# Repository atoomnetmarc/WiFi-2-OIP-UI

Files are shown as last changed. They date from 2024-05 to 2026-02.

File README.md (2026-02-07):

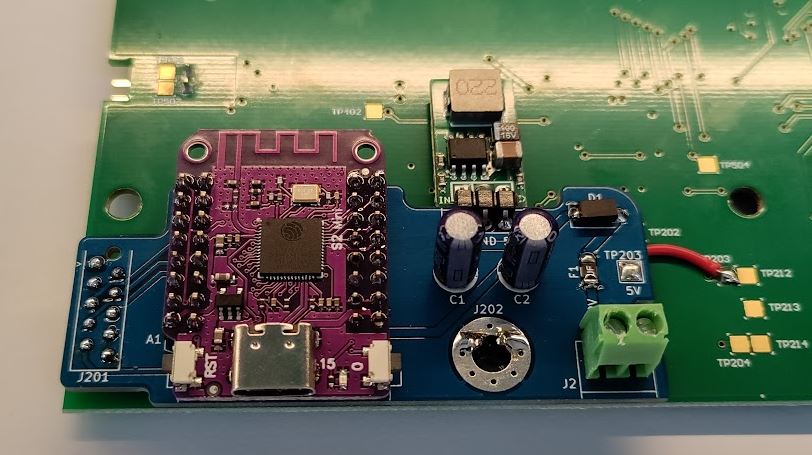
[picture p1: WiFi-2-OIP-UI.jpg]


# Status

Unfinished. Untested.

# What?

This is a **WiFi-connected display with LEDs** that gives new life to a reclaimed display board from an obsolete [Octalarm-IP](https://www.adesys.nl/en/product-octalarm-ip-adesys2).

The project consists of:

- A custom PCB that hosts an **ESP32-S2** microcontroller with WiFi connectivity
- A **128x64 LCD display** (Crystal Clear Technology G64128S18YBW00 with NT7534 controller)
- **20 red and 20 green LEDs** for status indication
- **Backlight control** for the LCD

The ESP32-S2 controls the display and LEDs via SPI.

# BOM

See: [Kicad/bom/ibom.html](Kicad/bom/ibom.html)

## BOM remarks

U1 should be a 5V buck converter in the footprint of a TO-220. It should be capable of outputting 5V at 1A. Input voltage should be greater than 12V.

J201 are 2 pieces of 1x05 2.54mm pp low profile (7.5mm) pin header instead of a Micro-MaTch connector.

For connecting TP203 you need 2cm of red wire.

The ESP32-S2 should come with 2 pieces of 2x08 2.54mm pin headers. Discard them and order 4 pieces of 1x08 2.54mm pp low profile (7.5mm) pin headers.

J201 Phoenix contact 1803277+1851999 can also be 1803277+1803578.

# Soldering and assembly instructions

Solder the pin headers on the ESP32-S2, use some old IDC connectors to perfectly align the headers. Like this:

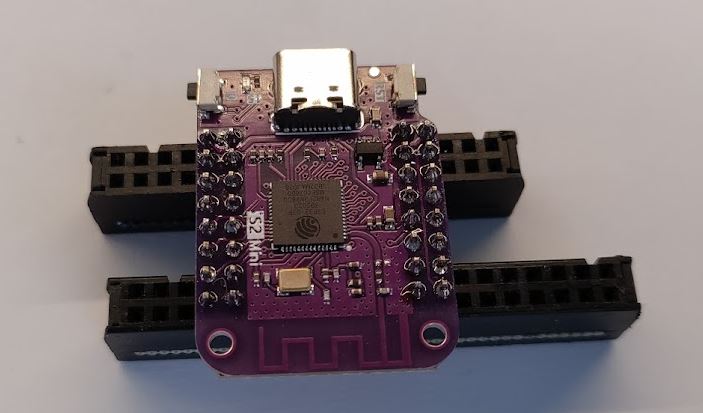
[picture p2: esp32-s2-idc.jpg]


Solder F1, D1. Solder U1 (the buck converter) laying flat (PCBs are now on the same plane). Cut pins (6 cuts) of U1 flush with PCB. Solder J2, C1 and C2. Cut pins of J2 flush with PCB. Solder one end of the red wire to TP203 on the bottom. The right side of the PCB now look like this:

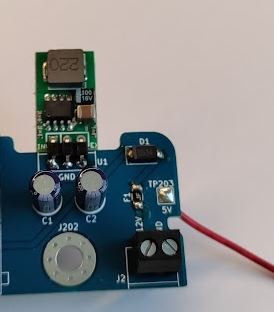
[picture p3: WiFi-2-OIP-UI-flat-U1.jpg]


Set your lab power supply to 12V CV, 0.25A CC. Then connect 12V to J2. Observe less than 10mA current. Measure 5V between TP203 and ground. Disconnect power supply.

Passed? Now solder A1 (the ESP32-S2 module). Do you not use low profile pin headers? Then cut pins flush with PCB. Works best before soldering.

Connect power supply again. Observe about 10mA current if ESP32-S2 is new and empty or about 40mA when flashed with firmware. Disconnect power supply.

Desolder the J201 MicroMatch 1.27mm socket from the display board.

Gently clean the PCB and the ESP32-S2 if you want.

Connect this PCB to the back of the display board using 2 pieces of low profile 1x5 2.54mm pin headers in the J201 footprints of both PCBs. The hole J202 on both PCB should almost align. But do not solder the header yet.
First solder a 1x02 2.54mm pin header on J202 of both PCBs to keep PCBs separated. Now solder the J201 pin header.

Solder the red wire onto the TP203 pad of the display board.

Connect power supply again. Observe about 20mA current (or 50mA when flashed). Disconnect power supply.

Make sure none of the pins (ESP32-S2, U1, J2) of this PCB touch display board:

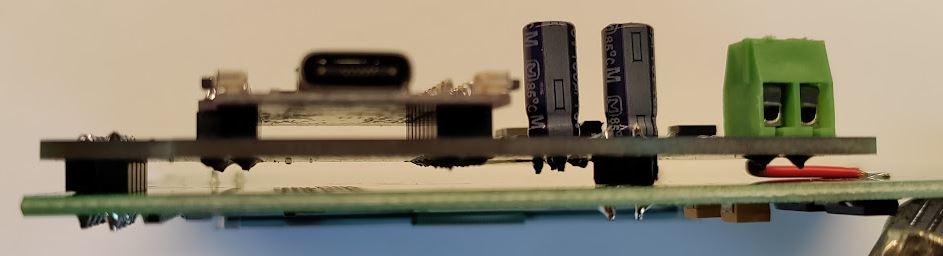
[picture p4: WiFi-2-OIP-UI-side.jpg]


# Firmware

Flash the firmware of the ESP32-S2. The firmware of the ATmega48 MCU of the display board is embedded in the ESP32-S2 firmware and will be flashed by the ESP32-S2.

# 3D-printed stand

You could 3d-print [a stand](3d/WiFi-2-OIP-UI%20stand.stl) for this contraption.

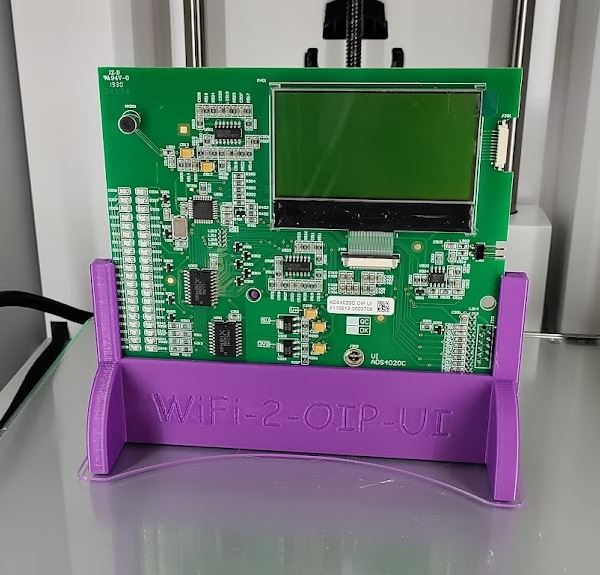
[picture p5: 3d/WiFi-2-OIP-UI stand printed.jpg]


# Display board

Information about the display board.

## Pinout J201

| # | name | remarks | ESP32 pin |
| --- | --- | --- | --- |
| 1 | GND | |
| 2 | V+ | unused |
| 3 | MCU reset | | IO5 |
| 4 | MCU interrupt | active low | IO1 |
| 5 | LCD RS | | IO4 |
| 6 | SPI clock | | IO7 |
| 7 | SPI MISO | | IO9 |
| 8 | SPI MOSI | | IO11 |
| 9 | SPI SS LCD | active low | IO14 |
| 10  | SPI SS MCU | active low | IO12 |

## LCD

LCD is a 128x64 Crystal Clear Technology [G64128S18YBW00](https://www.arrow.com/en/products/g64128s18ybw00/crystal-clear-technology-sdn-bhd). It contains a [Novatek NT7534](https://www.crystalfontz.com/controllers/Novatek/NT7534/) controller.

When testing with [U8g2](https://github.com/olikraus/u8g2) using U8G2_ST7565_ERC12864_ALT results in a working LCD.

## MCU

The MCU is a TQFP-32 [Atmega48](https://www.microchip.com/en-us/product/atmega48) that is responsible for driving the 20 red and 20 green LEDs and the backlight of the LCD.

## Testpoints

| # | name | remarks  |
| ----- | --- | --- |
| TP201 | MCU PD1 | not used |
| TP202 | V+ | not used |
| TP203 | 5V |
| TP204 | 3.3V |
| TP205 | MCU PC5, PC6  | not used |
| TP206 | SPI clock |
| TP207 | SPI MISO |
| TP208 | SPI MOSI |
| TP209 | MCU SS |
| TP210 | MCU reset |
| TP211 | MCU interrupt |
| TP212 | 5V |
| TP213 | GND |
| TP214 | 3.3V |
| TP301 | | not used |
| TP302 | | not used |
| TP303 | | not used |
| TP304 | | not used |
| TP305 | | not used |
| TP306 | | not used |
| TP307 | | not used |
| TP308 | | not used |
| TP309 | | not used |
| TP310 | | not used |
| TP402 | LCD reset |
| TP404 | LCD SS |
| TP405 | LCD RS |
| TP501 | | not used |
| TP502 | | not used |
| TP503 | MCU ADC7 | not used |
| TP504 | MCU PB1 | not used |
| TP506 | | not used |
| TP507 | | not used |
| TP508 | | not used |



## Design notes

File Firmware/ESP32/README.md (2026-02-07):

# WiFi-2-OIP-UI ESP32

This is a proof of concept project that connects to WiFi, then connects to an MQTT broker. It publishes some device information to the MQTT broker, and subscribes to the `clockall/solartime` topic, displaying the payload on a small display.

## Configuration

1.  Copy `include/config-example.h` to `include/config.h`.
2.  Edit `include/config.h` and fill in your WiFi credentials and MQTT configuration.

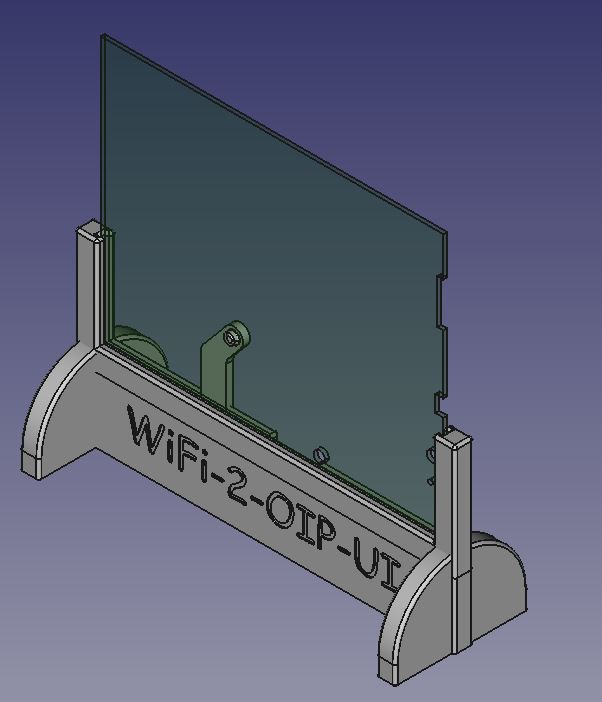
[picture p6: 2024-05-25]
3d/WiFi-2-OIP-UI stand.jpg

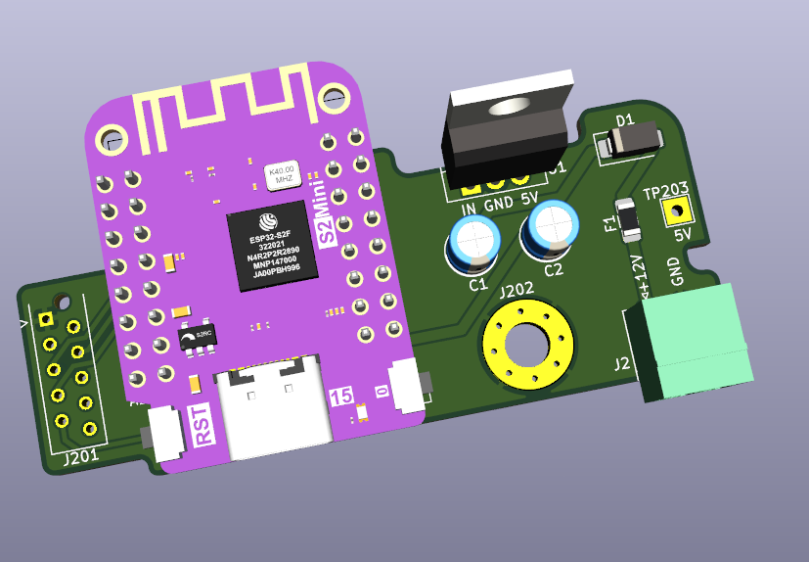
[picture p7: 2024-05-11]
Kicad/WiFi-2-OIP-UI-render.png

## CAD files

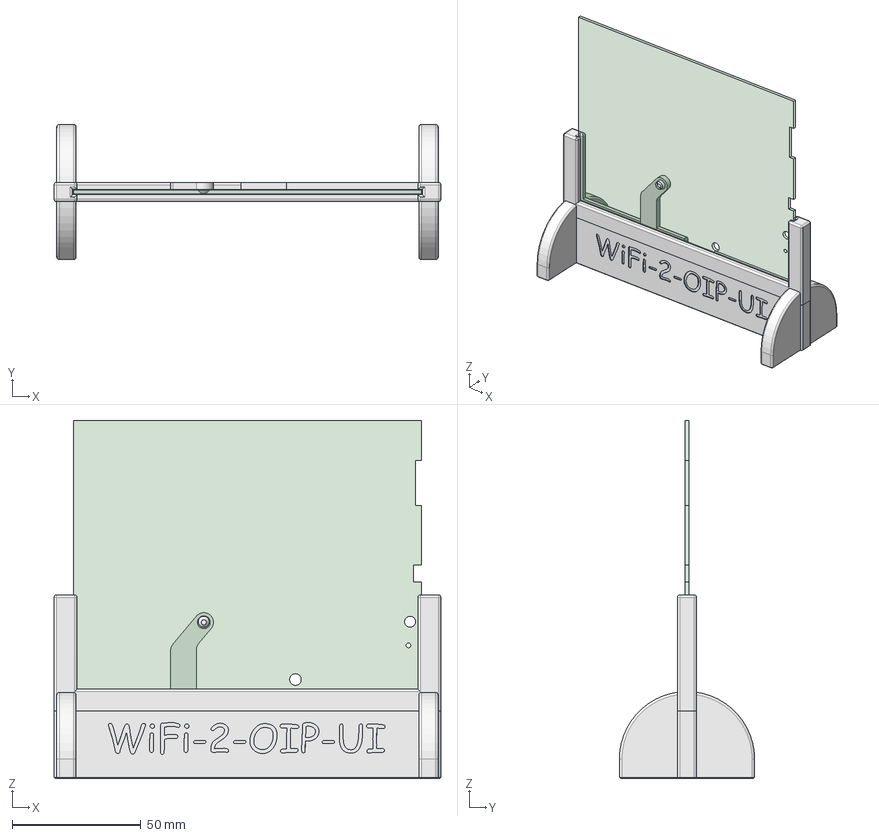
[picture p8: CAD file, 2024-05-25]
3d/WiFi-2-OIP-UI stand.FCStd
150.1 x 52.5 x 138.9 mm
Display pcb
pcb slot
pcb screwhole
Foot
Foot clone
pcb slot support

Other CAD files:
3d/WiFi-2-OIP-UI stand.stl

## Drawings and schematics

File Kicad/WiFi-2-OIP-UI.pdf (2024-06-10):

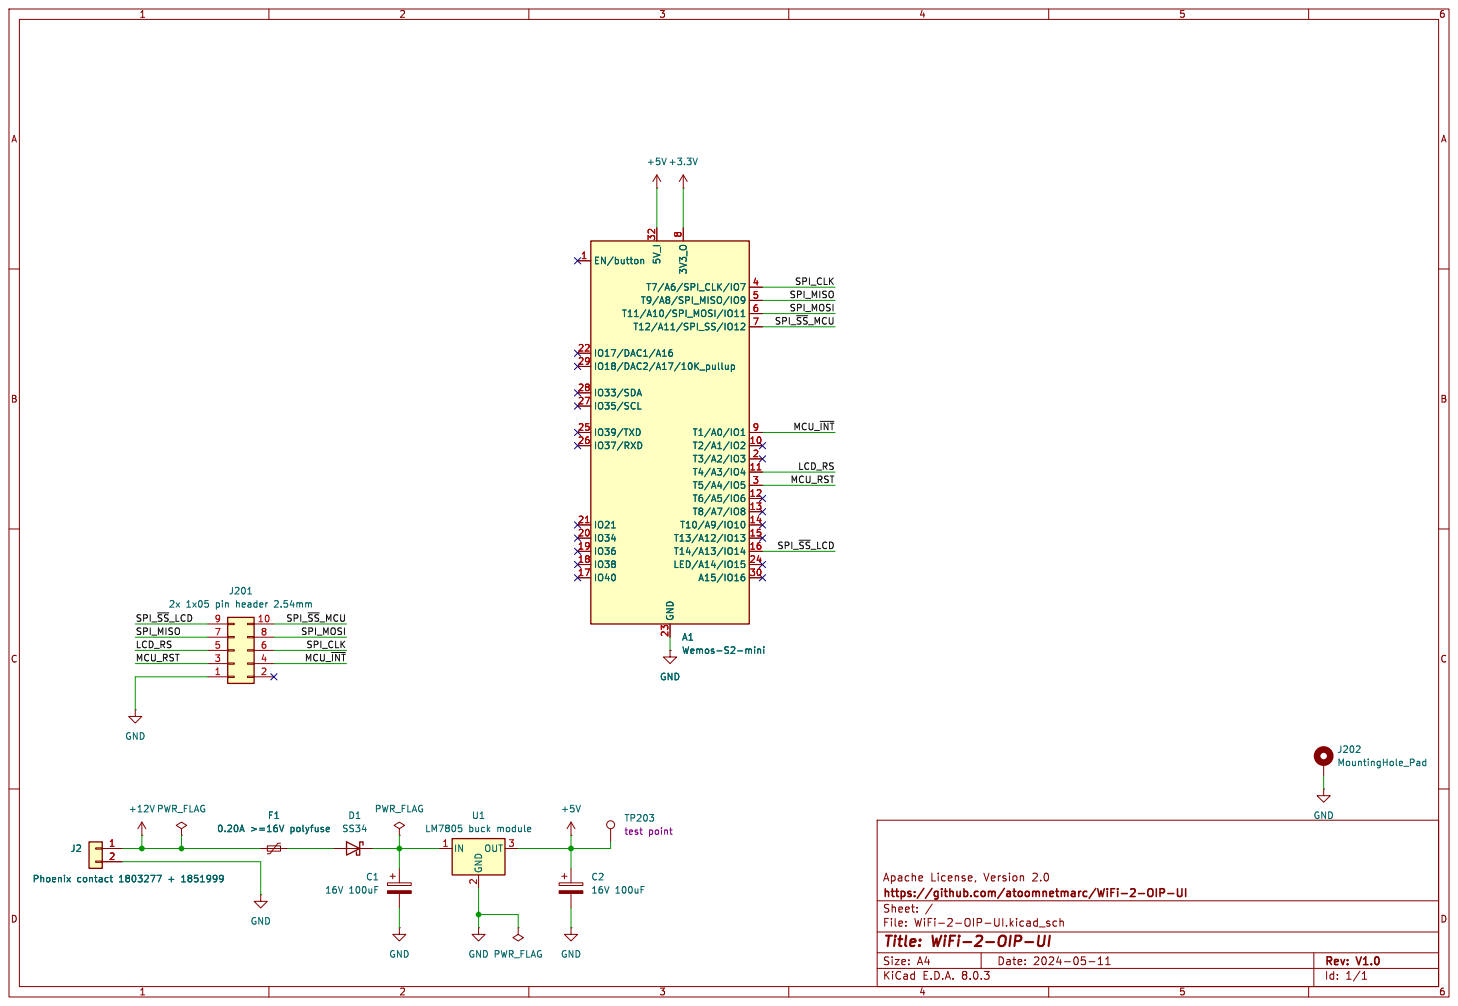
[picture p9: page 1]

Apache License, Version 2.0
Id: 1/1 Title: WiFi-2-OIP-UI File: WiFi-2-OIP-UI.kicad_sch Sheet: / https://github.com/atoomnetmarc/WiFi-2-OIP-UI

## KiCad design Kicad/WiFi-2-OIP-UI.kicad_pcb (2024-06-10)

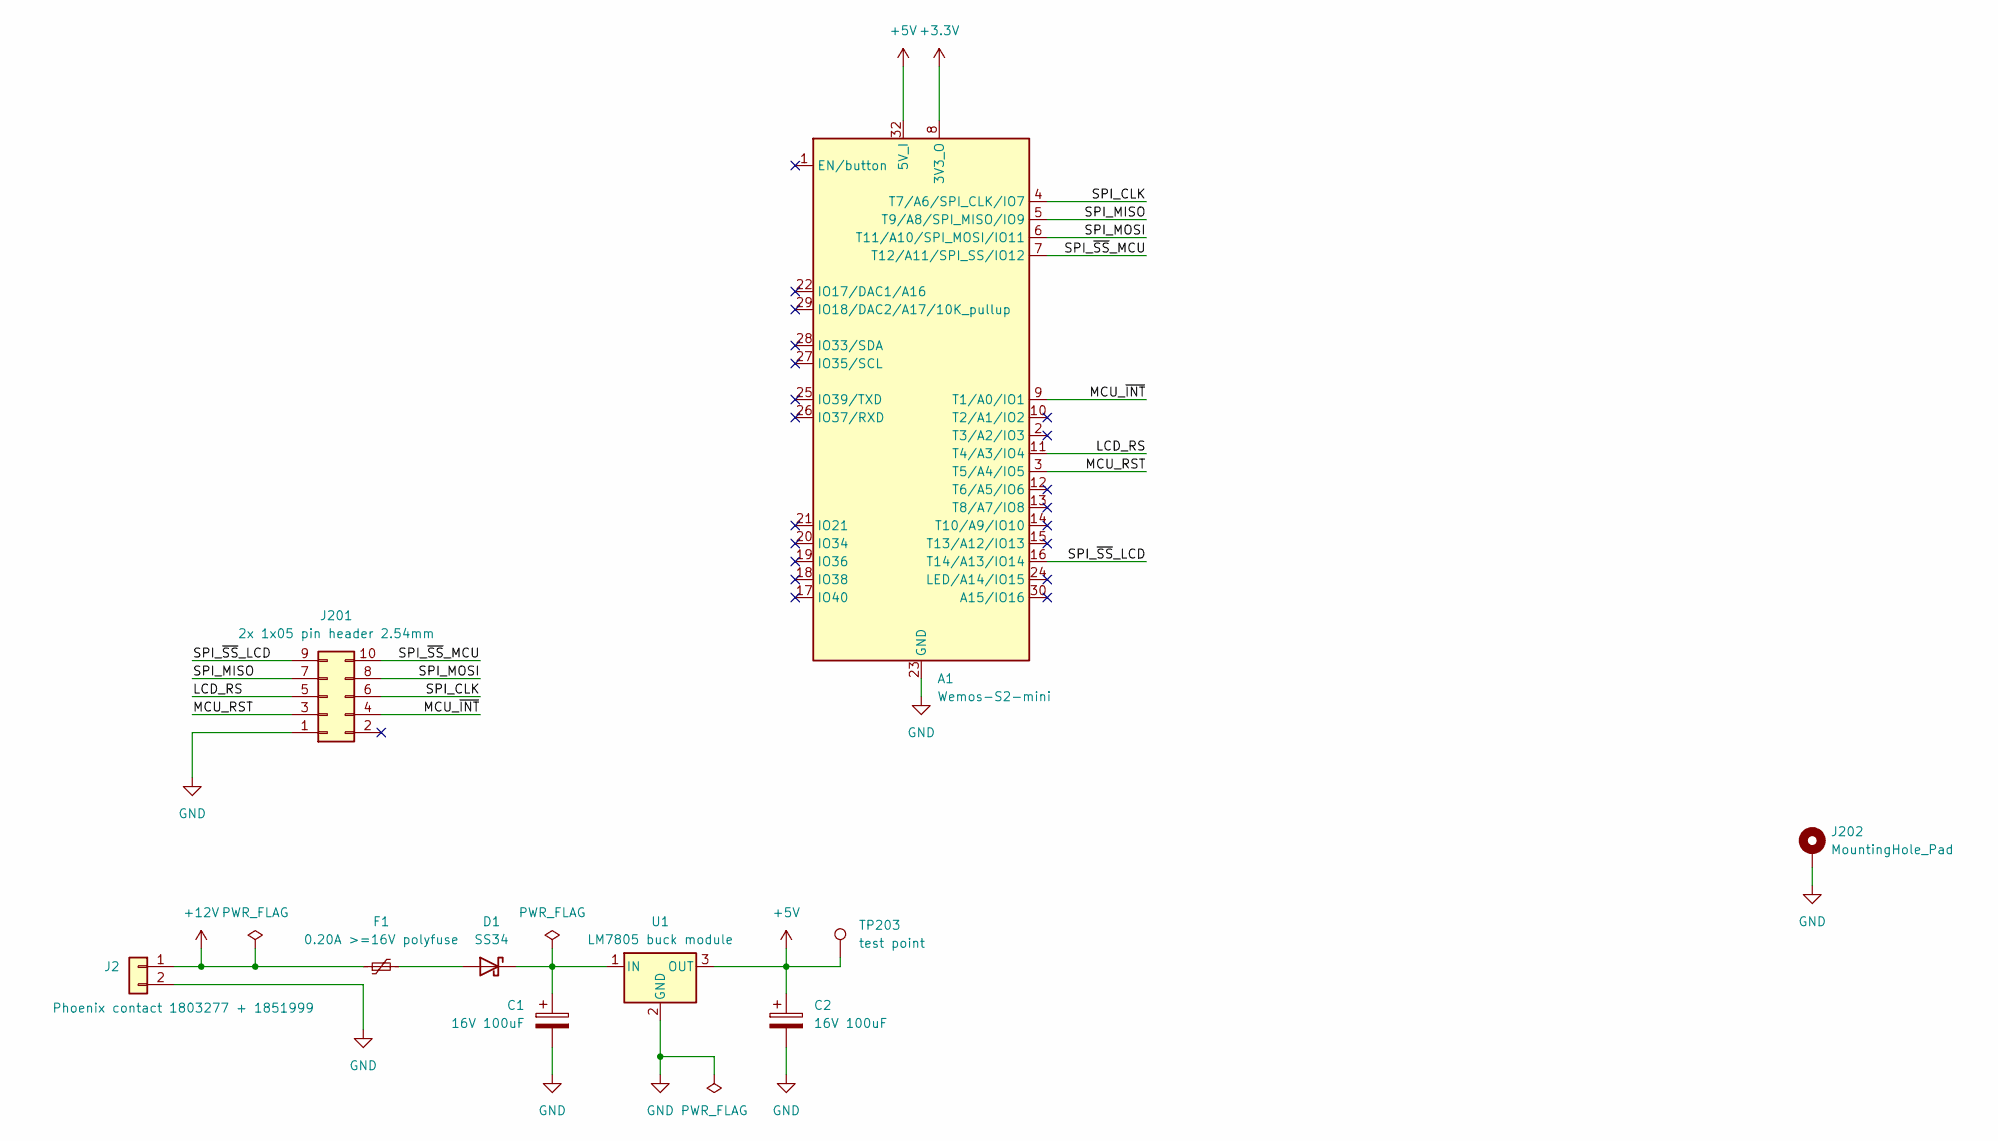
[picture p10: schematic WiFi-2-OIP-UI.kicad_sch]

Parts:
A1: Wemos-S2-mini
C1, C2: 16V 100uF; CP_Radial_D5.0mm_P2.00mm
D1: SS34; D_SMA
F1: 0.20A >=16V polyfuse; Fuse_1206_3216Metric_Pad1.42x1.75mm_HandSolder
J2: Phoenix contact 1803277 + 1851999; PhoenixContact_MC_1,5_2-G-3.5_1x02_P3.50mm_Horizontal
J201: 2x 1x05 pin header 2.54mm; TE_Micro-MaTch_1-215079-0_2x05_P1.27mm_Vertical
J202: MountingHole_Pad; MountingHole_4.5mm_Pad_Via
TP203: TestPoint; TestPoint_THTPad_2.5x2.5mm_Drill1.2mm
U1: LM7805 buck module; TO-220-3_Vertical

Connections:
+3.3V: A1.8 (3V3_O)
+5V: A1.32 (5V_I), C2.1, TP203.1, U1.3 (OUT)
+12V: F1.1, J2.1
/LCD_RS: A1.11 (T4/A3/IO4), J201.5
/MCU_RST: A1.3 (T5/A4/IO5), J201.3
/MCU_~INT: A1.9 (T1/A0/IO1), J201.4
/SPI_CLK: A1.4 (T7/A6/SPI_CLK/IO7), J201.6
/SPI_MISO: A1.5 (T9/A8/SPI_MISO/IO9), J201.7
/SPI_MOSI: A1.6 (T11/A10/SPI_MOSI/IO11), J201.8
/SPI_~SS_LCD: A1.16 (T14/A13/IO14), J201.9
/SPI_~SS_MCU: A1.7 (T12/A11/SPI_SS/IO12), J201.10
GND: A1.23 (GND), A1.31 (GND), C1.2, C2.2, J2.2, J201.1, J202.1, U1.2 (GND)
unnamed: D1.2 (A), F1.2
unnamed: C1.1, D1.1 (K), U1.1 (IN)

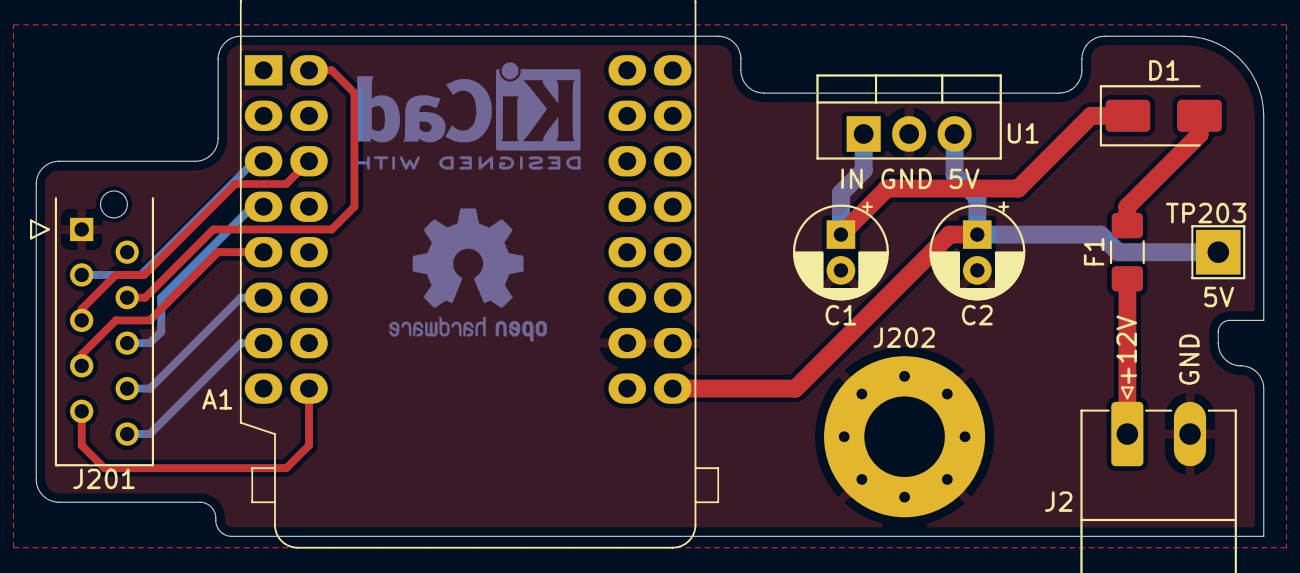
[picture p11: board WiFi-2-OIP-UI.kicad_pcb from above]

Board: 2 copper layers, 68.6 x 27.9 mm, 10 parts (0 on the bottom side), 13 nets.

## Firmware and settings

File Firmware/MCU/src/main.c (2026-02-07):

/*

Copyright 2024-2026 Marc Ketel
SPDX-License-Identifier: Apache-2.0

*/

#include <stdio.h>
#include <string.h>

#include <avr/eeprom.h>
#include <avr/interrupt.h>
#include <avr/io.h>
#include <avr/wdt.h>

#include <util/delay.h>

#include "event.h"
#include "fuses.h"
#include "instruction.h"
#include "io.h"
#include "message.h"
#include "node_firmware_build_time.h"
#include "timer.h"

// Test.
uint16_t EEMEM dummy = 0xABCD;

volatile MessageSystemInformation_u systemInfo = {};

// Define buffer size as header + largest message.
#define BUFFER_SIZE 1 + sizeof(MessageHeader_u) + sizeof(MessageLeds_u)

volatile uint8_t spiSlaveReceiveBuffer[BUFFER_SIZE];
volatile uint8_t spiSlaveReceiveBufferPointer = 0;

volatile uint8_t *spiSlaveTransmitData;
volatile uint8_t spiSlaveTransmitLength = 0;

void SPI_init_slave() {
    // Enable Pin Change Interrupt on falling edge of SS (PB2)
    PCICR |= _BV(PCIE0);   // Enable Pin Change Interrupt 0
    PCMSK0 |= _BV(PCINT2); // Enable interrupt on PB2 (SS)

    // Set SS (PB2) as input with pull-up resistor
    DDRB &= ~_BV(PB2);
    PORTB |= _BV(PB2);

    // Set MISO (PB4) as output
    DDRB |= _BV(PB4);

    // Enable SPI and SPI interrupt
    SPCR = _BV(SPE) | _BV(SPIE);
}

ISR(SPI_STC_vect) {
    // Save incoming data first.
    uint8_t receivedData = SPDR;

    // If this is the first byte since SS went low, then this is the instruction byte.
    if (spiSlaveReceiveBufferPointer == 0) {
        if (receivedData == INSTRUCTION_SYSTEMINFO_READ) {
            spiSlaveTransmitData = systemInfo.array;
            spiSlaveTransmitLength = sizeof(systemInfo.array);
        }
    }

    // Are we expected to send something?
    if (spiSlaveTransmitLength > 0) {
        SPDR = *spiSlaveTransmitData;

        spiSlaveTransmitData++;
        spiSlaveTransmitLength--;
    } else {
        SPDR = 0xFF;
    }

    if (spiSlaveReceiveBufferPointer < BUFFER_SIZE) {
        spiSlaveReceiveBuffer[spiSlaveReceiveBufferPointer] = receivedData;
        spiSlaveReceiveBufferPointer++;
    }
}

ISR(PCINT0_vect) {
    if ((PINB & _BV(PB2)) > 0) {
        event |= EV_SPI_SLAVE_TRANSACTION_COMPLETE;
        spiSlaveTransmitLength = 0;
    } else {
        spiSlaveReceiveBufferPointer = 0;
    }
}

void setup(void) {
    wdt_enable(WDTO_8S);

    memset(leds, ledStateOff, sizeof(leds));
    leds[40] = ledStateFadeOn; // LCD backlight.

    io_setup();
    event_setup();
    timer_setup();

    SPI_init_slave();

    sei();

    systemInfo.messageSystemInformationData.buildTime = NODE_FIRMWARE_BUILD_TIME;
}

void loop(void) {
    wdt_reset();

    while (event == 0) {
    }

    if (event & EV_TIMER_1MS) {
        event &= ~EV_TIMER_1MS;

        // Calculate new PWM target values of LEDS for the faster effects.
        static uint16_t updatePWMValuesCounterFast = 0;
        updatePWMValuesCounterFast++;
        if (updatePWMValuesCounterFast == 500 / LED_PWM_MAX) {
            updatePWMValuesCounterFast = 0;

            for (uint8_t i = 0; i < sizeof(leds); i++) {
                if (leds[i] == ledStateOff) {
                    ledsPWM[i] = 0;
                } else if (leds[i] == ledStateOn) {
                    ledsPWM[i] = LED_PWM_MAX;
                } else if (leds[i] == ledStateFadeOff && ledsPWM[i] > 0) {
                    ledsPWM[i]--;
                } else if (leds[i] == ledStateFadeOn && ledsPWM[i] < LED_PWM_MAX) {
                    ledsPWM[i]++;
                } else if (leds[i] == ledStateFadeBlinkOn && ledsPWM[i] < LED_PWM_MAX) {
                    ledsPWM[i]++;
                } else if (leds[i] == ledStateFadeBlinkOn && ledsPWM[i] == LED_PWM_MAX) {
                    leds[i] = ledStateFadeBlinkOff;
                } else if (leds[i] == ledStateFadeBlinkOff && ledsPWM[i] > 0) {
                    ledsPWM[i]--;
                } else if (leds[i] == ledStateFadeBlinkOff && ledsPWM[i] == 0) {
                    leds[i] = ledStateFadeBlinkOn;
                }
            }
        }

        // Calculate new PWM target values of LEDS for the slower effects.
        static uint16_t updatePWMValuesCounterSlow = 0;
        updatePWMValuesCounterSlow++;
        if (updatePWMValuesCounterSlow == 5000 / LED_PWM_MAX) {
            updatePWMValuesCounterSlow = 0;

            for (uint8_t i = 0; i < sizeof(leds); i++) {
                if (leds[i] == ledStateFadeBlinkSlowOn && ledsPWM[i] < LED_PWM_MAX) {
                    ledsPWM[i]++;
                } else if (leds[i] == ledStateFadeBlinkSlowOn && ledsPWM[i] == LED_PWM_MAX) {
                    leds[i] = ledStateFadeBlinkSlowOff;
                } else if (leds[i] == ledStateFadeBlinkSlowOff && ledsPWM[i] > 0) {
                    ledsPWM[i]--;
                } else if (leds[i] == ledStateFadeBlinkSlowOff && ledsPWM[i] == 0) {
                    leds[i] = ledStateFadeBlinkSlowOn;
                } else if (leds[i] == ledStateFadeSlowOff && ledsPWM[i] > 0) {
                    ledsPWM[i]--;
                } else if (leds[i] == ledStateFadeSlowOn && ledsPWM[i] < LED_PWM_MAX) {
                    ledsPWM[i]++;
                }
            }
        }
    }

    if (event & EV_SPI_SLAVE_TRANSACTION_COMPLETE) {
        event &= ~EV_SPI_SLAVE_TRANSACTION_COMPLETE;

        uint8_t offset = 0;
        uint8_t instruction = spiSlaveReceiveBuffer[offset];
        offset += sizeof(instruction);
        if (instruction == INSTRUCTION_MESSAGE_WRITE) {
            MessageHeader_u *mu = (MessageHeader_u *)&spiSlaveReceiveBuffer[offset];
            offset += sizeof(mu->array);

            if (mu->messageHeader.id == MESSAGE_ID_LEDS) {
                MessageLeds_u *ml = (MessageLeds_u *)&spiSlaveReceiveBuffer[offset];
                offset += sizeof(ml->array);

                for (uint8_t i = 0; i < sizeof(ml->array); i++) {
                    leds[i] = ml->array[i];
                }
            } else if (mu->messageHeader.id == MESSAGE_ID_LCD_RESET) {
                lcdReset = 0;
            }
        }
    }
}

__attribute__((OS_main)) int main(void) {
    setup();

    for (;;) {
        loop();
    }
}

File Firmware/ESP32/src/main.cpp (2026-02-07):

/*

Copyright 2024-2026 Marc Ketel
SPDX-License-Identifier: Apache-2.0

*/

#include <Arduino.h>
#include <SPI.h>
#include <Ticker.h>
#include <U8g2lib.h>

#include <AvrIspProgrammer.h>

#include "instruction.h"
#include "message.h"
#include "spi_config.h"

#include "time.h"

#include "../MCU/include/node_firmware.h"
#include "../MCU/include/node_firmware_build_time.h"

#include "config.h"
#include "display.h"
#include "main.h"
#include "mqtt.h"
#include "wific.h"

Ticker tickerReadSystemInformation;
Ticker tickerNodeDoSomething;

#define SPI_MODE_NETWORK 0
#define SPI_MODE_ISP     1
volatile uint8_t spiMode = SPI_MODE_NETWORK;

void ReadSystemInformation() {
    if (spiMode != SPI_MODE_NETWORK) {
        return;
    }

    SPI.beginTransaction(SPISettings(SPI_CLK, MSBFIRST, SPI_MODE0));
    digitalWrite(M_CS, LOW);

    MessageSystemInformation_u si = {};
    SPI.transfer(INSTRUCTION_SYSTEMINFO_READ);
    for (uint8_t i = 0; i < sizeof(si.array); i++) {
        si.array[i] = SPI.transfer(0xFF);
    }

    digitalWrite(M_CS, HIGH);
    SPI.endTransaction();

    Serial.print(F("Node firmware build time: "));
    Serial.println(si.messageSystemInformationData.buildTime);

    // Must the node be flashed?
    if (si.messageSystemInformationData.buildTime != NODE_FIRMWARE_BUILD_TIME) {
        Serial.println(F("Node should be programmed, buildTime of firmware is different."));
        spiMode = SPI_MODE_ISP;
        SPI.end();
        digitalWrite(LED_BUILTIN, HIGH);
        uint8_t result = programNode();
        digitalWrite(LED_BUILTIN, LOW);
        SPI.begin(M_SCK, M_MISO, M_MOSI, M_CS);
        spiMode = SPI_MODE_NETWORK;

        if (result == 0) {
            Serial.println("Programming of node succeeded.");
        } else {
            Serial.println("Programming of node failed.");
        }
    }
    tickerReadSystemInformation.detach();

    // At this point the node is probably ready to process commands.
}

uint8_t programNode() {
    if (spiMode != SPI_MODE_ISP) {
        Serial.println(F("Refusing to program node. spiMode is not SPI_MODE_ISP."));
        return 0;
    }

    if (AvrIspProgrammerEnableSerialProgramming() != 1) {
        Serial.println(F("Unable to enter AVR into programming mode."));
        return 1;
    }

    uint8_t signature[3];
    AvrIspProgrammerReadSignature(signature);

    if (signature[0] != node_signature[0] ||
        signature[1] != node_signature[1] ||
        signature[2] != node_signature[2]) {
        Serial.println(F("Signature of AVR not as expected."));
        return 2;
    }

    FuseBits_t fusebits;
    AvrIspProgrammerReadFuseBits(&fusebits);

    uint8_t erased = 0;
    FuseBits_t targetfusebits = {node_fuse[0], node_fuse[1], node_fuse[2]};
    if (fusebits.low != targetfusebits.low ||
        fusebits.high != targetfusebits.high ||
        fusebits.extended != targetfusebits.extended) {
        AvrIspProgrammerChipErase();
        erased = 1;
        AvrIspProgrammerWriteFuseBits(&targetfusebits);
        Serial.println(F("Fuses of AVR programmed."));
    }

    uint8_t flashcontentsequal = 1;
    for (size_t i = 0; i < sizeof(node_flash); i++) {
        uint8_t currentFlash = AvrIspProgrammerReadProgramMemory(i);

        if (node_flash[i] != currentFlash) {
            flashcontentsequal = 0;
            break;
        }
    }

    if (!flashcontentsequal) {
        Serial.println(F("Programming flash."));
        if (!erased) {
            AvrIspProgrammerChipErase();
        }
        uint8_t pagesizeBytes = 32 * 2; // ATmega48 page size in bytes.
        uint8_t pageByteCounter = 0;
        size_t j = 0;
        for (size_t i = 0; i < sizeof(node_flash); i++) {
            AvrIspProgrammerLoadProgramMemoryPage(pageByteCounter, node_flash[i]);

            if (++pageByteCounter == pagesizeBytes ||
                i == sizeof(node_flash) - 1) {
                AvrIspProgrammerWriteMemoryPage(j);
                pageByteCounter = 0;
                j = i + 1; // Save start address of flash to program page for later.
            }
        }
    } else {
        Serial.println(F("Flash not programmed. Flash is the same as the new firmware."));
    }
    AvrIspProgrammerDisableSerialProgramming();

    Serial.println(F("Programming done."));
    return 0;
}

void NodeDoSomething() {
    Serial.println(F("NodeDoSomething()"));
    if (spiMode != SPI_MODE_NETWORK) {
        return;
    }

    static MessageLeds_u ml = {};

    ml.messageLeds.backlight = ledStateOn;

    ml.messageLeds.red[0] = ledStateOff;
    ml.messageLeds.red[1] = ledStateOn;
    ml.messageLeds.red[2] = ledStateFadeOff;
    ml.messageLeds.red[3] = ledStateFadeOn;
    ml.messageLeds.red[4] = ledStateFadeSlowOff;
    ml.messageLeds.red[5] = ledStateFadeSlowOn;
    ml.messageLeds.red[6] = ledStateFadeBlinkOn;
    ml.messageLeds.red[7] = ledStateFadeBlinkOff;
    ml.messageLeds.red[8] = ledStateFadeBlinkSlowOn;
    ml.messageLeds.red[9] = ledStateFadeBlinkSlowOff;

    if (ml.messageLeds.green[0] == ledStateFadeOn) {
        Serial.println(F("Off"));
        ml.messageLeds.green[0] = ledStateOff;
    } else {
        Serial.println(F("On"));
        ml.messageLeds.green[0] = ledStateFadeOn;
    }

    MessageHeader_u mh = {};
    mh.messageHeader.id = MESSAGE_ID_LEDS;
    mh.messageHeader.length = sizeof(ml.array);

    SPI.beginTransaction(SPISettings(SPI_CLK, MSBFIRST, SPI_MODE0));
    digitalWrite(M_CS, LOW);

    SPI.transfer(INSTRUCTION_MESSAGE_WRITE);
    for (uint8_t i = 0; i < sizeof(mh.array); i++) {
        SPI.transfer(mh.array[i]);
    }
    for (uint8_t i = 0; i < sizeof(ml.array); i++) {
        SPI.transfer(ml.array[i]);
    }

    digitalWrite(M_CS, HIGH);
    SPI.endTransaction();
}

/**
 * @brief Arduino setup function.
 *
 * This function is called once at the beginning of the program. It initializes the display,
 * connects to WiFi, initializes the MQTT client, and subscribes to relevant topics.
 */
void setup() {
    pinMode(LED_BUILTIN, OUTPUT);
    digitalWrite(LED_BUILTIN, HIGH);
    setCpuFrequencyMhz(80);
    Serial.begin(115200);

    // Wait a while for USB serial connection.
    /*
    uint32_t counter = 0;
    while (!Serial && counter++ < 100) {
        delay(100);
    }
    */

    Serial.println(F("Booting"));

    configTime(0, 0, NTP_SERVER);

    digitalWrite(M_RESET, HIGH);
    pinMode(M_RESET, OUTPUT);
    pinMode(M_INT, PULLUP);
    pinMode(M_CS, OUTPUT);
    digitalWrite(M_CS, HIGH);

    SPI.begin(M_SCK, M_MISO, M_MOSI);

    tickerReadSystemInformation.attach_ms(100, ReadSystemInformation);
    tickerNodeDoSomething.attach_ms(1000, NodeDoSomething);

    WificSetup();
    MqttSetup();
    DisplaySetup();
    RequestDrawDisplay();

    digitalWrite(LED_BUILTIN, LOW);
    Serial.print(F("My hostname: "));
    Serial.println(hostname);
}
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

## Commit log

2024-05-11 Initial commit.
    [WiFi-2-OIP-UI-B_Cu.gbl, WiFi-2-OIP-UI-B_Mask.gbs, WiFi-2-OIP-UI-B_Paste.gbp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]
2024-05-23 Add soldering and assembly instructions.
2024-05-24 Add MCU code to control LEDs.
2024-05-24 Add documentation about display board.
2024-05-25 Add 3d-printable stand.
    [WiFi-2-OIP-UI stand.FCStd, WiFi-2-OIP-UI stand.stl]
2024-06-10 Change fuse to 0.2A
    [WiFi-2-OIP-UI.kicad_pcb, WiFi-2-OIP-UI.kicad_sch]
2024-06-10 Soldered a few pcbs, made changes to instructions.
2025-03-30 Create proof-of-concept code for esp32.

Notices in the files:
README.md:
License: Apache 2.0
